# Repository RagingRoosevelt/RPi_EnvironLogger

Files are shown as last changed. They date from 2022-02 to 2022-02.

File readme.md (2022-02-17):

# Raspberry Pi Environmental Data Logger

This project sets up a data logging system for my raspberry pi to monitor
temperature, relative humidity, and CO2 levels.  It presumes you have an
available postgres database to log to.  It also presumes that your Raspberry Pi
has an internet connection.

## Hardware Setup

Adafruit's i2c sensors are very well set up with excelent python integration.
For this project, I used

* [SCD-30](https://www.adafruit.com/product/4867) real CO2 reading which
handles CO2 PPM, % relative humidity, and temperature
* [DS3231](https://www.adafruit.com/product/5188) Real Time Clock (RTC) and
temperature source #2
* [TMP117](https://www.adafruit.com/product/4821) temperature source #3
* [MCP9808](https://www.adafruit.com/product/5027) temperature source #4
* [Stemma QT SHIM](https://www.adafruit.com/product/4463) for easy connection
of the sensors

I opted to use PoE to power my Raspberry Pi since I needed to get a network
connection to it anyhow.  I'm cheap so I used Adafruit's
[USB C PoE Splitter](https://www.adafruit.com/product/4552) (but you can find
them on other online stores too) rather than using a PoE hat.  This also
simplified making the "case" for my setup.

I designed and 3D printed a ["lid"](./Case/Lid.stl) and
[mount panel](Case/Mount.stl) that I could use plastic standoffs to attach
everyting with.  I used M2 standoffs so that I'd have a bit more tollerance
in the hole layouts.  I went with
[this set of standoffs](https://www.amazon.com/gp/product/B01DMJVQVC/) which
includes various lengths of standoffs in addition to M2 plastics screws and M2
nuts.

I used some Dual Lock velcro to affix the Pi and PoE splitter to a beam in my
crawl space.  I used a low-voltage in-wall mounting box/bracket and a
keystone-compatible face plate with some keystone Cat6 female-to-female coupler
jacks to pass ethernet through my wall from my network closet into my crawl
space.

Installed, it looks like this:

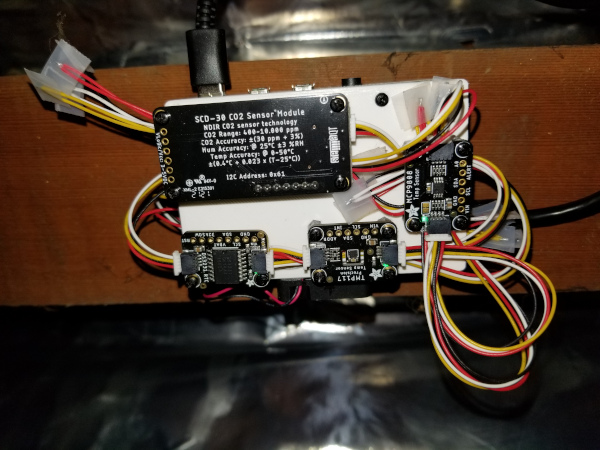
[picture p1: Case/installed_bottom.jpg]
Photo of Raspberry Pi installed in crawl space, from the bottom

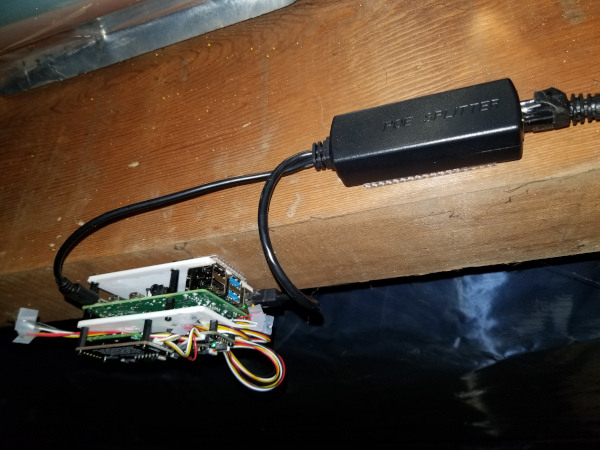
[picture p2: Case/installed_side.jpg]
Photo of Raspberry Pi installed in crawl space, from the side


## Database Setup

1. Make sure an instance of postgres running somewhere
2. If a new database is needed, set that up
3. Use the contents in the [`ddl.sql`][ddl] file to set up a table,
modify as needed

Note: I used heroku's postgres hosting. They have a free tier that supports
10,000 rows and 20 connections.  This system only uses 1 or 2 connections
and at 15 minute logging frequency, that's 96 records per day or around 100
days of logging.  One caviat with using Heroku is that they ocasionally
perform database "maintaince" that results in the hostname, database name,
user name, and password being changed.  They email before this happens but it
can still be a bit of a hastle.  In the future, I think I'll either install
postgres on the Pi, or once I get my container cluster running, host a
general-purpose postgres database there instead.

[ddl]: ./ddl.sql

## Software Setup

Fill out the [`logging_config_template.ini`][template] file with the pertinent
info.  A copy of this file is used both on the pi and locally for reporting.

[template]: ./logging_config_template.ini

### Logger

1. Set up a Raspberry Pi, probably with raspbian or debian or a similar OS
2. Make sure there's a running ssh server on the pi
3. Install python 3 if it isn't already installed
4. Copy the [`requirements-pi_logger.txt`][req_pi], [`env_logger.py`][script],
and filled out `logging_config.ini` to the pi and make sure the `.ini` and
`.py` files are in the same directory
5. Install the requirements file with
`python -m pip install -r requirements-pi_logger.txt`
6. Set up the `.py` file to be run automatically when the pi launches, perhaps
by
    * Adding a cron entry
      1. Launch cron editor: `crontab -u pi -e`
      2. Add a line like `@reboot python3 /home/pi/env_logger.py`
      3. Save and exit the editor
      4. Reboot
    * Adding it to `rc.local`
      * Untested, but probably with
`su pi -c 'python3 /home/pi/env_logger.py &'`
    * Adding a script to the `init.d` directory
    * SYSTEMD

[req_pi]: ./RPi_Logger/requirements-pi_logger.txt
[script]: ./RPi_Logger/env_logger.py

### Reporting

1. Make sure you have a python 3 environment
2. Install [library requirements][req_rept] with
`python -m pip install -r requirements-local_reports.txt`
3. Copy the filled out `logging_config.ini` file to where you store the
[`plot.ipynb`][plot] file
4. Launch jupyter lab (or use something like VSC) from the same directory as
the ploting notebook
6. Run the notebook to see the plots, optionally edit the query or save the
image

Outputs should look something like

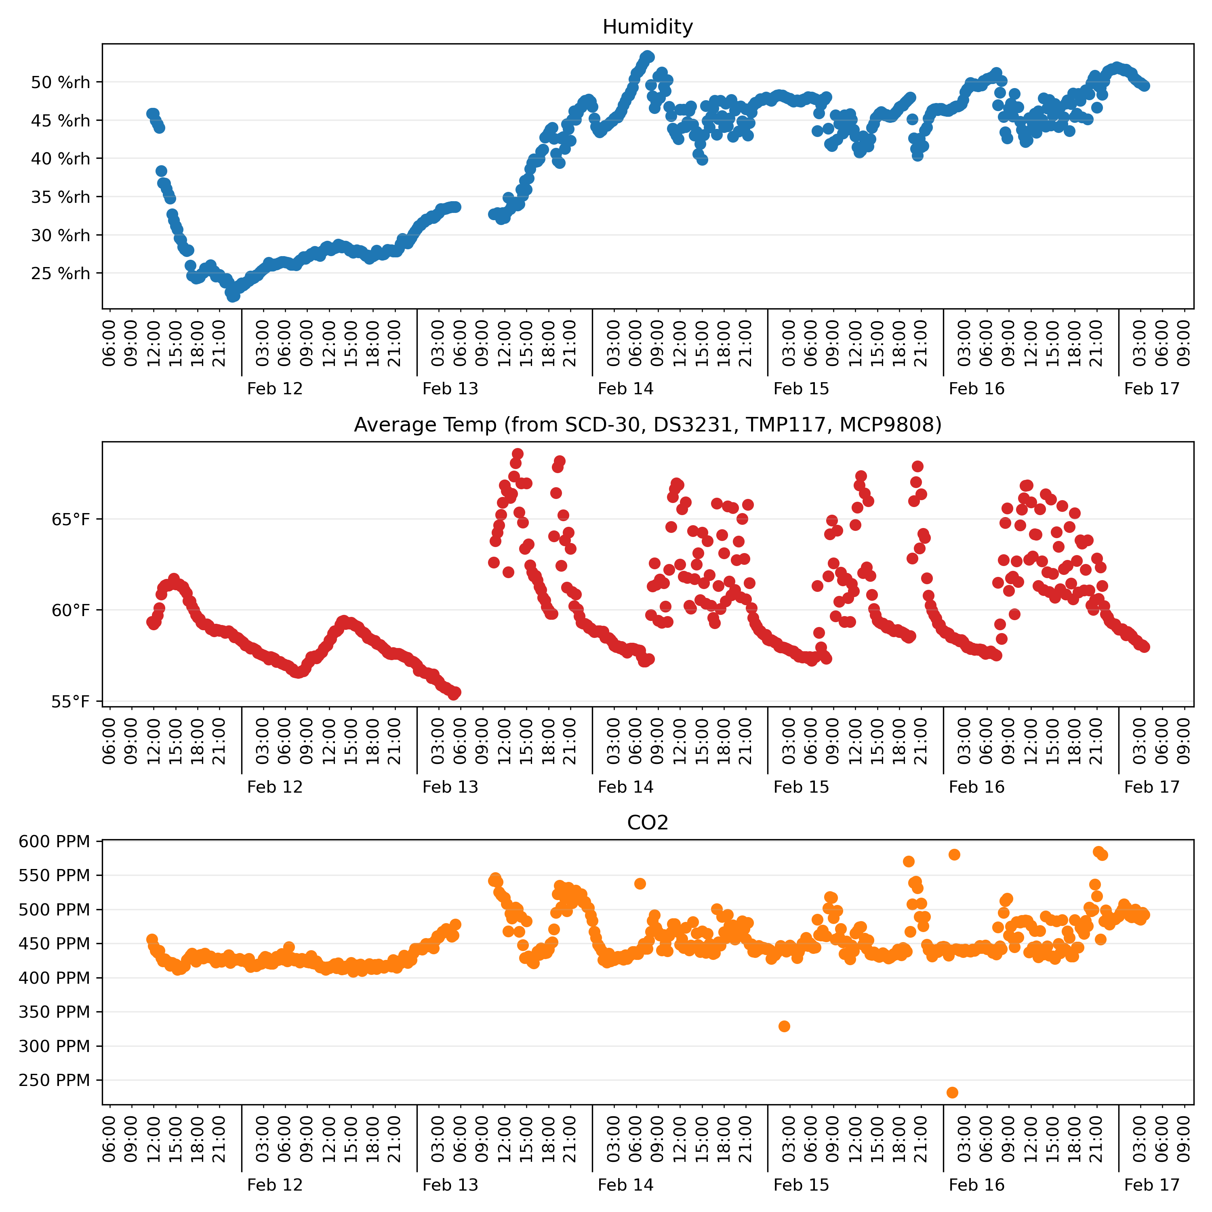
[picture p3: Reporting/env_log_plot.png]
Demo output figure from reporting notebook


Note: I suspect that the erratic data shown in this demo is due to the
proximity of my Pi to my HVAC ducts.  I'm planning to either move the Pi
away from the ducts or distribute the temperature sensors around the crawl
space rather than having them all mounted together.

[req_rept]: ./Reporting/requirements-local_reports.txt
[plot]: ./Reporting/plot.ipynb

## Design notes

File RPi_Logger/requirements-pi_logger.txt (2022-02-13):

psycopg2-binary
pytz

# https://learn.adafruit.com/circuitpython-on-raspberrypi-linux/installing-circuitpython-on-raspberry-pi
Adafruit-Blinka
adafruit_scd30
adafruit_ds3231
adafruit_mcp9808
adafruit_tmp117

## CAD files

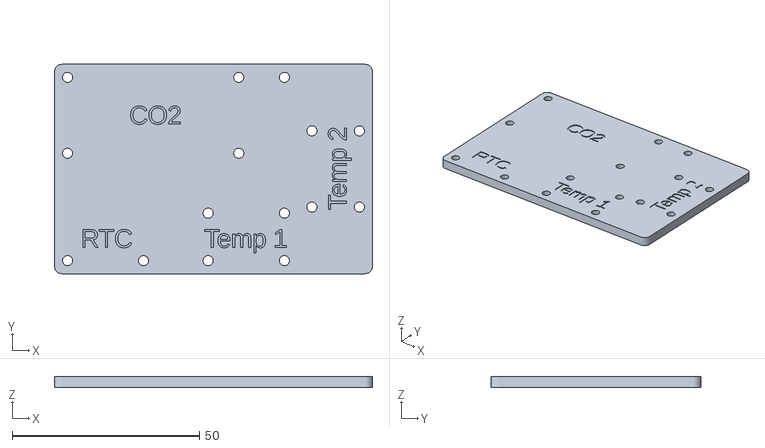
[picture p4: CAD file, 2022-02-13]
Case/Mount.stl
85.0 x 56.0 x 3.00

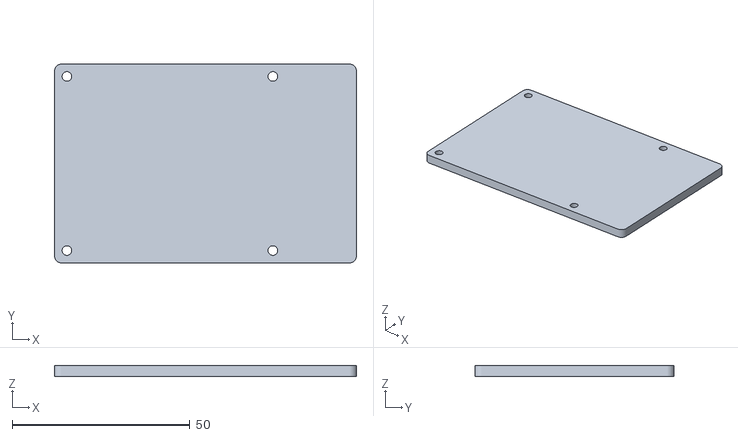
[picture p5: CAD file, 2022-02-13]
Case/Lid.stl
85.0 x 56.0 x 3.00

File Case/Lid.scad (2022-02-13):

$fn=100;
difference() {
cube(
  size=[85,56,3],
  center=false
);
// SW
translate([
    2.7/2+2.15,
    2.7/2+2.15,
    -5
    ])
cylinder(
  h=10,
  r=2.7/2,
  center=false
);
// NW
translate([
    2.7/2+2.15,
    56-2.7/2-2.15,
    -5
    ])
cylinder(
  h=10,
  r=2.7/2,
  center=false
);
// SE
translate([
    2.7/2+2.15+57.95,
    2.7/2+2.15,
    -5
    ])
cylinder(
  h=10,
  r=2.7/2,
  center=false
);
// NE
translate([
    2.7/2+2.15+57.95,
    56-2.7/2-2.15,
    -5
    ])
cylinder(
  h=10,
  r=2.7/2,
  center=false
);
difference() {
    cube([4,4,7],center=true);
    translate([2,2,-4])
    cylinder(h=8,r=2);
}
translate([85,0,0])
rotate(90,[0,0,1])
difference() {
    cube([4,4,7],center=true);
    translate([2,2,-4])
    cylinder(h=8,r=2);
}
translate([0,56,0])
rotate(-90,[0,0,1])
difference() {
    cube([4,4,7],center=true);
    translate([2,2,-4])
    cylinder(h=8,r=2);
}
translate([85,56,0])
rotate(180,[0,0,1])
difference() {
    cube([4,4,7],center=true);
    translate([2,2,-4])
    cylinder(h=8,r=2);
}
}

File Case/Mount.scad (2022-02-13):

$fn=100;
translate([0,0,1])
difference() {
translate([0,0,-1])
cube(
  size=[85,56,3],
  center=false
);
// SW
translate([
    2.7/2+2.15,
    2.7/2+2.15,
    -5
    ])
cylinder(
  h=10,
  r=2.7/2,
  center=false
);
// NW
translate([
    2.7/2+2.15,
    56-2.7/2-2.15,
    -5
    ])
cylinder(
  h=10,
  r=2.7/2,
  center=false
);
// SE
translate([
    2.7/2+2.15+57.95,
    2.7/2+2.15,
    -5
    ])
cylinder(
  h=10,
  r=2.7/2,
  center=false
);
// NE
translate([
    2.7/2+2.15+57.95,
    56-2.7/2-2.15,
    -5
    ])
cylinder(
  h=10,
  r=2.7/2,
  center=false
);
// RTC holes
translate([
    2.7/2+2.15+20.3,
    2.7/2+2.15,
    -5
    ])
cylinder(
  h=10,
  r=2.7/2,
  center=false
);
//translate([
//    2.7/2+2.15+20.3,
//    2.7/2+2.15,
//    -2.001
//    ])
//cylinder(
//    h=1,
//    r1=2.1,
//    r2=1.1,
//    center=false
//);
// temp1 NE
translate([
    2.7/2+2.15+57.95,
    2.7/2+2.15+12.7,
    -5
    ])
cylinder(
  h=10,
  r=2.7/2,
  center=false
);
//translate([
//    2.7/2+2.15+57.95,
//    2.7/2+2.15+12.7,
//    -2.001
//    ])
//cylinder(
//    h=1,
//    r1=2.1,
//    r2=1.1,
//    center=false
//);
// temp1 SW
translate([
    2.7/2+2.15+57.95-20.375,
    2.7/2+2.15,
    -5
    ])
cylinder(
  h=10,
  r=2.7/2,
  center=false
);
//translate([
//    2.7/2+2.15+57.95-20.375,
//    2.7/2+2.15,
//    -2.001
//    ])
//cylinder(
//    h=1,
//    r1=2.1,
//    r2=1.1,
//    center=false
//);
// temp1 NW
translate([
    2.7/2+2.15+57.95-20.375,
    2.7/2+2.15+12.7,
    -5
    ])
cylinder(
  h=10,
  r=2.7/2,
  center=false
);
//translate([
//    2.7/2+2.15+57.95-20.375,
//    2.7/2+2.15+12.7,
//    -2.001
//    ])
//cylinder(
//    h=1,
//    r1=2.1,
//    r2=1.1,
//    center=false
//);
// temp2 SW
translate([
    85-2.15-2.7/2-12.7,
    2.7/2+2.15+14.3125,
    -5
    ])
cylinder(
  h=10,
  r=2.7/2,
  center=false
);
//translate([
//    85-2.15-2.7/2-12.7,
//    2.7/2+2.15+14.3125,
//    -2.001
//    ])
//cylinder(
//    h=1,
//    r1=2.1,
//    r2=1.1,
//    center=false
//);
// temp2 NW
translate([
    85-2.15-2.7/2-12.7,
    2.7/2+2.15+14.3125+20.375,
    -5
    ])
cylinder(
  h=10,
  r=2.7/2,
  center=false
);
//translate([
//    85-2.15-2.7/2-12.7,
//    2.7/2+2.15+14.3125+20.375,
//    -2.001
//    ])
//cylinder(
//    h=1,
//    r1=2.1,
//    r2=1.1,
//    center=false
//);
// temp2 SE
translate([
    85-2.15-2.7/2,
    2.7/2+2.15+14.3125,
    -5
    ])
cylinder(
  h=10,
  r=2.7/2,
  center=false
);
//translate([
//    85-2.15-2.7/2,
//    2.7/2+2.15+14.3125,
//    -2.001
//    ])
//cylinder(
//    h=1,
//    r1=2.1,
//    r2=1.1,
//    center=false
//);
// temp2 NE
translate([
    85-2.15-2.7/2,
    2.7/2+2.15+14.3125+20.375,
    -5
    ])
cylinder(
  h=10,
  r=2.7/2,
  center=false
);
//translate([
//    85-2.15-2.7/2,
//    2.7/2+2.15+14.3125+20.375,
//    -2.001
//    ])
//cylinder(
//    h=1,
//    r1=2.1,
//    r2=1.1,
//    center=false
//);
// co2 SW
translate([
    2.7/2+2.15,
    56-2.7/2-2.15-20.3,
    -5
    ])
cylinder(
  h=10,
  r=2.7/2,
  center=false
);
//translate([
//    2.7/2+2.15,
//    56-2.7/2-2.15-20.3,
//    -2.001
//    ])
//cylinder(
//    h=1,
//    r1=2.1,
//    r2=1.1,
//    center=false
//);
// co2 SE
translate([
    2.7/2+2.15+45.75,
    56-2.7/2-2.15-20.3,
    -5
    ])
cylinder(
  h=10,
  r=2.7/2,
  center=false
);
//translate([
//    2.7/2+2.15+45.75,
//    56-2.7/2-2.15-20.3,
//    -2.001
//    ])
//cylinder(
//    h=1,
//    r1=2.1,
//    r2=1.1,
//    center=false
//);
// co2 NE
translate([
    2.7/2+2.15+45.75,
    56-2.7/2-2.15,
    -5
    ])
cylinder(
  h=10,
  r=2.7/2,
  center=false
);
//translate([
//    2.7/2+2.15+45.75,
//    56-2.7/2-2.15,
//    -2.001
//    ])
//cylinder(
//    h=1,
//    r1=2.1,
//    r2=1.1,
//    center=false
//);
translate([7,7,1.8])
linear_extrude(4)
text("RTC",5);
translate([20,40,1.8])
linear_extrude(4)
text("CO2",5);
translate([78,17,1.8])
rotate(90,[0,0,1])
linear_extrude(4)
text("Temp 2",5);
translate([40,7,1.8])
linear_extrude(4)
text("Temp 1",5);

difference() {
    cube([4,4,7],center=true);
    translate([2,2,-4])
    cylinder(h=8,r=2);
}
translate([85,0,0])
rotate(90,[0,0,1])
difference() {
    cube([4,4,7],center=true);
    translate([2,2,-4])
    cylinder(h=8,r=2);
}
translate([0,56,0])
rotate(-90,[0,0,1])
difference() {
    cube([4,4,7],center=true);
    translate([2,2,-4])
    cylinder(h=8,r=2);
}
translate([85,56,0])
rotate(180,[0,0,1])
difference() {
    cube([4,4,7],center=true);
    translate([2,2,-4])
    cylinder(h=8,r=2);
}
}







// rpi lng: 60.65 - 55.25 = 57.95
// rpi srt: 51.7  - 46.3  = 49

// co2 lng: 48.25 - 43.25 = 45.75
// co2 srt: 22.75 - 17.85 = 20.3

// tmp lng: 22.75 - 18    = 20.375
// tmp srt: 15.15 - 10.25 = 12.7

// rtc lng: 23.3  - 17.3  = 20.3

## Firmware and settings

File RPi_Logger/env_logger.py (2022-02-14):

import time
import board
import adafruit_scd30
import adafruit_ds3231
import adafruit_mcp9808
import adafruit_tmp117
import psycopg2
from pytz import timezone
from datetime import datetime, timedelta

from pathlib import Path
from configparser import ConfigParser

# Pull config from ini file
conf = ConfigParser()
conf.read(Path(__file__).parent / 'logging_config.ini')

# Establish an on-going database connection
conn = psycopg2.connect(
    host=conf['postgres'].get('hostname'),
    database=conf['postgres'].get('database'),
    port=conf['postgres'].get('port', 5432),
    user=conf['postgres'].get('username'),
    password=conf['postgres'].get('password')
)
cur = conn.cursor()

# Connect to the I2C devices
i2c = board.I2C()
scd = adafruit_scd30.SCD30(i2c)
rtc = adafruit_ds3231.DS3231(i2c)
tmp = adafruit_tmp117.TMP117(i2c)
mcp = adafruit_mcp9808.MCP9808(i2c)

log_freq = int(conf['logging'].get('frequency_min', 15))
log_location = conf['logging'].get('location_name', 'unspecified location')
local_timezone = timezone(conf['logging'].get('local_timezone', 'UTC'))

# Functions to determine how long to sleep in order to hit logging frequency
sleep_time = lambda _dt: 60*(log_freq - (dt.minute % log_freq) - 1) + (60 - dt.second)
get_dt = lambda _rtc: datetime.fromtimestamp(time.mktime(_rtc.datetime)).replace(tzinfo=timezone('UTC'))

# Sleep until next interval
dt = get_dt(rtc)
st = sleep_time(dt)
print(
    "Current time is %s UTC"%dt.strftime("%Y-%m-%d %H:%M:%S"),
    "Waiting %s minutes and %s seconds to start logging" %(st//60, st%60),
    "Logging starting at %s UTC"%(dt+timedelta(seconds=st)).strftime("%H:%M:%S"),
    "",
    sep='\n'
)
time.sleep(sleep_time(get_dt(rtc)))

while True:
    try:
        # Fetch data from the sensors
        datum = dict(
            loc=log_location,
            tsl=get_dt(rtc),
            hum=scd.relative_humidity,
            co2=scd.CO2,
            mcp=mcp.temperature,
            tmp=tmp.temperature,
            scd=scd.temperature,
            rtc=rtc.temperature,
            avg=0.25*(mcp.temperature+tmp.temperature+scd.temperature+rtc.temperature)
        )
        if True:
            # Log recording timestamp and some of the data
            dt = get_dt(rtc)
            print(
                datum['tsl'].strftime("[%Y-%m-%d %H:%M:%S UTC]"),
                datum['tsl'].astimezone(local_timezone).strftime("[%Y-%m-%d %H:%M:%S Local]"),
                f'Sleeping {sleep_time(dt)} seconds',
                f" - {datum['co2']: 10.3f} PPM",
                f" - {datum['avg']: 10.1f}C"
            )
        else:
            print(
                "===========================",
                datum['tsl'].astimezone(local_timezone).strftime("[%Y-%m-%d %H:%M:%S Local]"),
                "",
                f"{datum['co2']: 10.3f} PPM",
                f"{datum['hum']: 10.3f} %rH",
                "",
                "Average Temp\tMCP9808\tTMP117\tSCD-30\tRTC\t\t",
                "{avg:0.2f}\N{DEGREE SIGN}C\t\t"
                "{mcp:0.2f}\N{DEGREE SIGN}C\t{tmp:0.2f}\N{DEGREE SIGN}C"
                "\t{scd:0.2f}\N{DEGREE SIGN}C\t{rtc:0.2f}\N{DEGREE SIGN}C".format(
                    **{k:v for k,v in datum.items() if k in ('mcp','tmp','scd','rtc','avg')}
                ),
                sep='\n'
            )
        # Push a record to the database
        cur.execute(
            """
                insert into env_log (
                    location,ts_load_utc,humidity,co2,
                    temp_mcp,temp_tmp,temp_scd,temp_rtc,temp_avg
                )
                values
                (%(loc)s,%(tsl)s,%(hum)s,%(co2)s,%(mcp)s,%(tmp)s,%(scd)s,%(rtc)s,%(avg)s)
            """,
            {**datum, 'tsl': datum['tsl'].strftime("%Y-%m-%dT%H:%M:%SZ")}
        )
        conn.commit()
    except OSError as ex:
        print("===========================")
        print(ex)

    # Sleep until next cycle
    time.sleep(sleep_time(get_dt(rtc)))

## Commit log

2022-02-13 Initial version
    [Lid.scad, Lid.stl, Mount.scad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]
2022-02-13 fixed issue with mismatching ts_load column names
    [env_logger.py]
